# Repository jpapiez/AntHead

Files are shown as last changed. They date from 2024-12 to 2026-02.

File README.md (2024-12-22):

# AntHead
Toolhead for Micron and other PFA printers (Can also work on bigger 2020 based printers with the carriages linked below)


## BOM 
* 2x 4010 blower fans 
* 1x 2510 axial fan 
* various m3 hardware 
* BMG extruder kit , or G2 extruder kit (HGX variant is planned)
* Dragon Compatible hotend, Revo Voron, Rapido, TZV6 with or without v6 nozzle
* NOTE: if using a TZV6 hotend with the stock nozzle (small bambu style nozzle) you need to use the dragon hotend mount

when mounting the fans, the front cover needs to be removed prior to screwing it down with 2 m2x6 


What Carriage Do I Print?

Printer  | Rail 
 ----|----|
Micron/SF/Pandora | Stock [MGN9H](https://github.com/PrintersForAnts/Micron/blob/main/STLs/Gantry/Toolhead/MiniSB/MiniSB_x_carriage_MGN9H_x1.stl) | 
Micron/SF/Pandora | Stock [MGN9C](https://github.com/PrintersForAnts/Micron/blob/main/STLs/Gantry/Toolhead/MiniSB/miniSB_x_carriage_x1.stl) |
Micron/SF/Pandora | Chirpy  [MGN9H](https://github.com/chirpy2605/voron/blob/main/general/Alternative_Voron_Mounts/Modified_Mounts/Micron_Pandora/STLs/X_Carriage_MGN9H_Micron_Long.stl)
Micron/SF/Pandora | Chirpy [MGN9C](https://github.com/chirpy2605/voron/blob/main/general/Alternative_Voron_Mounts/Modified_Mounts/Micron_Pandora/STLs/X_Carriage_MGN9C_Micron_Long.stl)
V0 | Stock works but i recommend Chirpys that can be found [here](https://github.com/chirpy2605/voron/blob/main/general/Alternative_Voron_Mounts/Modified_Mounts/v0.2) 
V2/Trident | Chirpys DB [MGN12H](https://github.com/chirpy2605/voron/tree/main/general/Alternative_Voron_Mounts/Modified_Mounts/V1_V2/STLs/MGN12H)
V2/Trident | Chirpys DB [MGN9H](https://github.com/chirpy2605/voron/tree/main/general/Alternative_Voron_Mounts/Modified_Mounts/V1_V2/STLs/MGN9H)

## Future Plans ##
* HGX Based extruder
* Revisit BMG based extruder
* Bowden option
* Filament cutter (in beta on discord)
* larger variety of hotend mounts

## Change log ##

### 10-30-2024
* Updated CAD to v29
* missed exporting latest right fan ducts from previous commit, they worked but had an extra chamfer that needed to be removed  

### 10-29-2024 #2
* modified main housing to now support Sherpa bolt pattern as well as Orbiter 2 bolt pattern
* ducts were updated to fit the latest change
* a Base Grill cad file was uploaded so custom grills can be made 

### 10-29-2024 #1
* Fixed an issue that was introduced with the latest LED changes from 10-28
* updated main housings, and Cad file

### 10-28-2024
* Updated assembly to v20
* Updated the LED to use the same style as Stealthburner that inserts from the bottom 
* Fixed orientation of various files 

### 10-17-2024
* Added latest CAD assembly
* removed recesses in main housing as they arent needed anymore since hotend mount screws are recessed into the printed part
* added a Voron logo variant of the main body 
* added LED logo parts for both Micron and Voron logo 
* added a dual filament sensor WWG2 variant extruder as the default extruder option in CAD 
* organized files a bit more

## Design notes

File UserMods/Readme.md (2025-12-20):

# Anthead Mods

Various mods for AntHead project
Remember to update this README when uploading new mod!

Update the following table with the information about your mod:
- Your name
- A link to your sub-folder
- A short description of your mod
- On which version of the Anthead is this mod made

| Creator | Mod title | Description | Based on Version
| --- | --- | --- | --- |
| Averen | [LED Solder Fixture](/UserMods/LED_Solder_Fixture) | Fixture for soldering up Nozzle LEDs and Body LED | Version V63 |
| Hoeby | [ZeroClick on left ducting](/UserMods/ZeroClick_left_ducting) | Using ZeroClick on the side, to keep space in the back | Version V43 |
|| [Mainbody HexZero logo](/UserMods/Main_Body_HexZero_logo) | The AntHead mainbody with the HexZero logo, incl. led | Version V43 |
| MakerMylo | [Screwless Hotend Fan Mount](/UserMods/Screwless_Hotend_Fan_Mount) | A mount for the hotend fan that uses pegs to attach to the hotend. | Version V50 |
| theFPVgeek | [Papilio Lite Extruder AntHead Mod](/UserMods/Papilio_Lite_Extruder_AntHead_Mod) | Papilio Lite Extruder modified for AntHead | Version V43 |
| Cyph3r42 | [Wristwatch-BMG dual sensor Extruder](/UserMods/Wristwatch-BMG) | A4T WW-BMG Extruder modified for AntHead | Version V72 |
| burkfers | [Bearing cutting surface](/UserMods/Bearing_cutting_surface) | Uses a small MR63 or 683 bearing as a shearing surface for leafcutter | Version V72 |
| hartk | [Crossbow](/UserMods/hartk/crossbow) | mount to use the crossbow filament cutter | latest |
|| [Trident Umbilical](/UserMods/hartk/Trident_Umbilcal) | umbilical mount for trident| latest |
| Suzuki | [WWG2 V0 Board Mount](/UserMods/WWG2_V0_Board_Mount/) | 4-point board mount for WWG2 on a Voron V0 | Version v96 |

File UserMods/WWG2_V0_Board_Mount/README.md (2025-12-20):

# V0 Board Mount

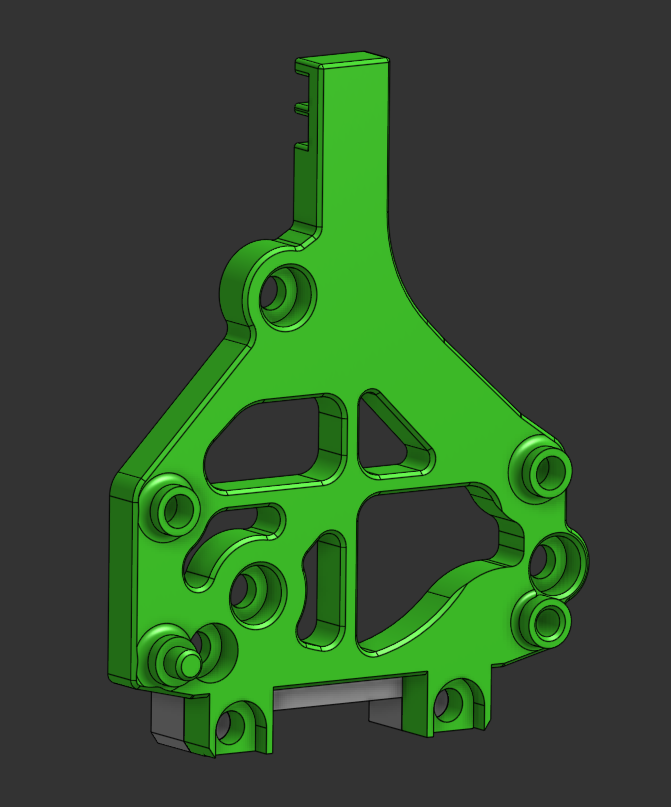
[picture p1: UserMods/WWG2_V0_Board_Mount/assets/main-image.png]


The micron mount colides with the motor mounts in the back, and the 2020 mount isnt rigid enough.

Hardware:

+ Stock hardware
+ 2x M3x12 screws

## Notes

+ There are 2 spacer versions, one for 20mm standoffs, and one for 16mm standoffs. They are `20-Spacer.stl` and `16-Spacer.stl` respectively.
+ The stock P.U.G holder won't work with 16mm standoffs. You'll have to make a custom one.
+ The spacer has to be mounted as shown in the image, or it will colide with the motor mounts.
+ The fit is a bit tight, so don't tighten the screws until they are all in correct positions.

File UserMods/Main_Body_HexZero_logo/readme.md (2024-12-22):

# MainBody with HexZero logo included led option
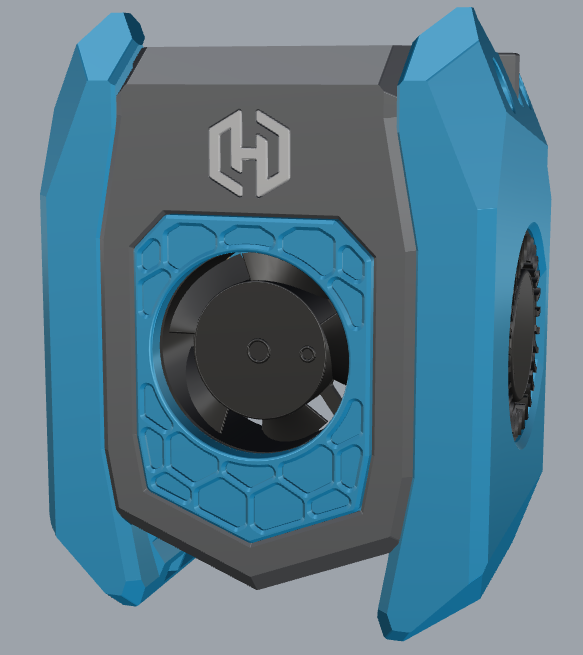
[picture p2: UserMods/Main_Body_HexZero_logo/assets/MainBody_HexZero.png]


This mod is made for the HexZero. <br>
[Github link HexZero](https://github.com/Alexander-T-Moss/Hex-Zero) 

## Which 3d parts are shared
Only the modded parts can be find in this mod. <br>
This includes the parts for the led. <br>
Non modded parts, that are the default AntHead parts and can be find in de main repository of the AntHead. <br>
The parts are made on AntHead version43

## Be carefull
Be carefull when you assemble the led.
Because of the design of the HexZero logo and the space that is availble, the parts are thin.
Take this in care, when you assemble the mainbody.

## Hardware needed for this mode
### For the AntHead
Nothing extra is needed for the AntHead, when looking at the hardware. <br>

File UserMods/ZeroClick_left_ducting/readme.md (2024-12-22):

# ZeroClick on left ducting
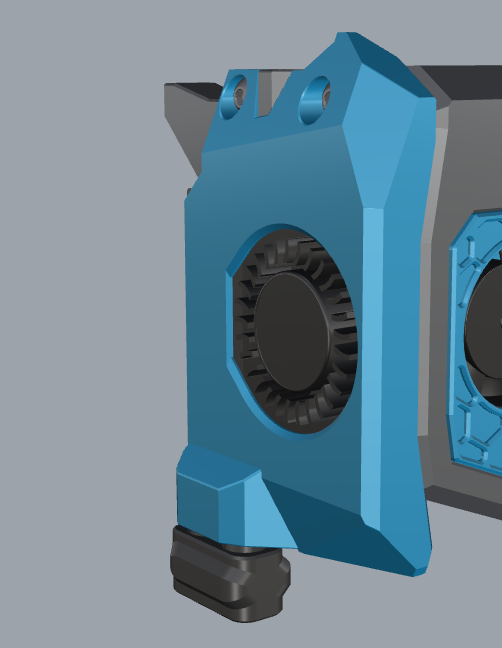
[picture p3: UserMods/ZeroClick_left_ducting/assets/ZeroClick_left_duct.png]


## Idea about this mod
This mod is started for the HexZero. <br>
The HexZero has the dual extrusions in the back, like the Voron V0.2. <br>
On the HexZero the change is made, that the gantry can move over these dual extrusions. <br>
There is that little space, that there can't be parts on the back of the toolhead, because these would collide with these Z-extrusions. <br>
This mod moves the probe to the side, to give free space on the back, to prevent this collision. <br>
[Github link HexZero](https://github.com/Alexander-T-Moss/Hex-Zero) 

## Which 3d parts are shared
Only the modded parts can be find in this mod. <br>
Non modded parts, that are the default AntHead parts and can be find in de main repository of the AntHead. <br>
Only the standard fan is modded. Other fan ductings are not changed, but could be done by de delivered CAD.

## Hardware needed for this mode
### For the AntHead
Nothing extra is needed for the AntHead, when looking at the hardware. <br>
### For the ZeroClick
The default parts for the ZeroClick are needed. <br>
Extra parts could be the parts for the dock, depends on the user choice, what to use. <br>
For the ZeroClick follow there github. <br>
[Github link ZeroClick](https://github.com/zruncho3d/ZeroClick) 

## How to wire the ducting
Before following the ZeroClick manual, the explanation how the wiring has to be done
### Step 1
Start by placing wire in the wire-guide of the front magnet-hole and let it stick out of the back. <br> 
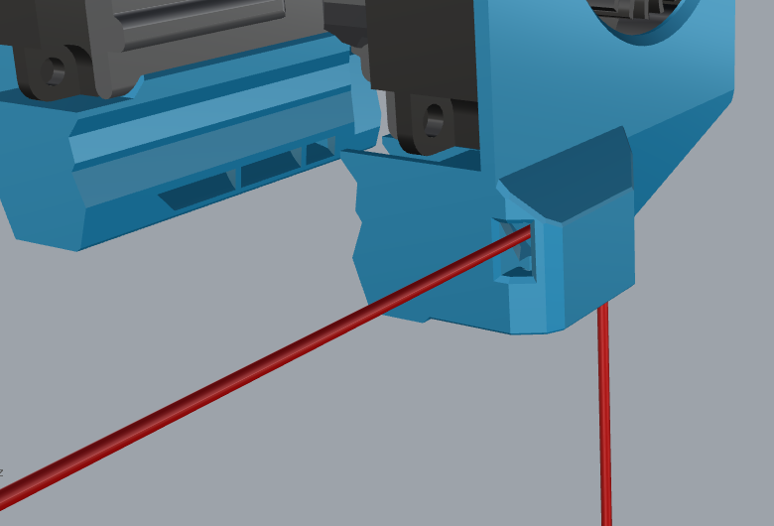
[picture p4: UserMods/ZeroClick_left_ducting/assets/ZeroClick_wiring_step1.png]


### Step 2
Loop back the wire and place it back in the hole it comes out, but now in the wire-guide that goes underneat the fan. <br> 
Carefully pull on the wire end and help them, that the loop disappears inside the ducting, and nothing is sticking out the back. <br>
Not easy to draw in Rhino, to make a wire loop, but you will get it what i mean :blush: <br>
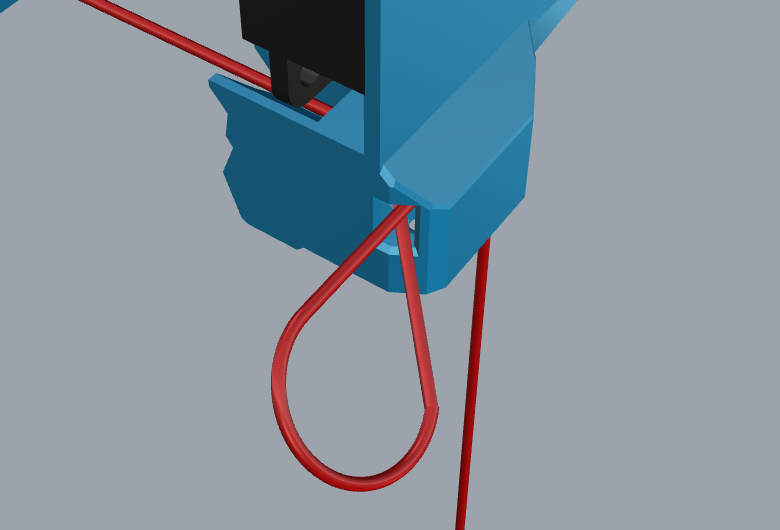
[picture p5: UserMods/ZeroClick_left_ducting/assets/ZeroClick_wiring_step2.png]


### Step 3
Place the wire-guide of the back magnet-hole. <br> 
This wire-guide hole is almost in line with the wire-guide underneat the fan, that you can route it in a single job. <br>
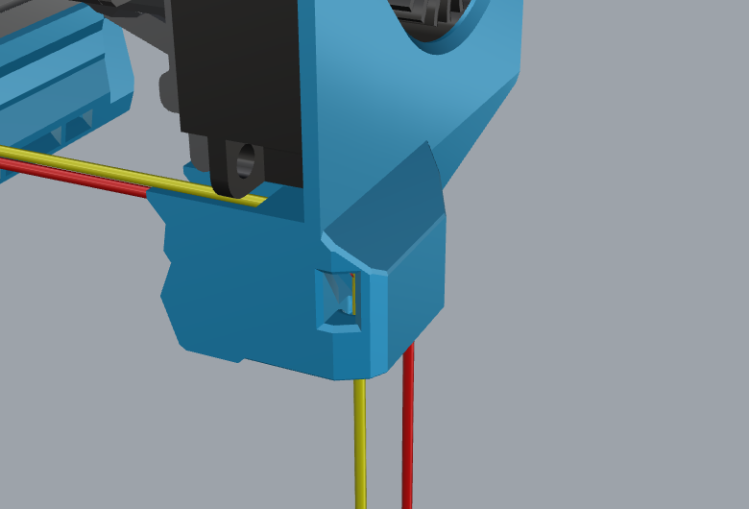
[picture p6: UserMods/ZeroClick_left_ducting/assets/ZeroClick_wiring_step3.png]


### Step 4
Now that the ZeroClick wires are near the fan, follow the wire route of the fan.
How to finish the wiring for the ZeroClick magnets, see the ZeroClick manual on there github

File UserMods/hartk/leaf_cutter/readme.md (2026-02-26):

Leaf Cutter filament cutter. 

This is no longer going to be updated by me (Hartk), with the release of Crossbow CNC cutter that is my recommendation for a filament cutter for anthead. If anyone wants to iterate on this and make it better be my guest , make a PR and ill merge it into this usermods folder

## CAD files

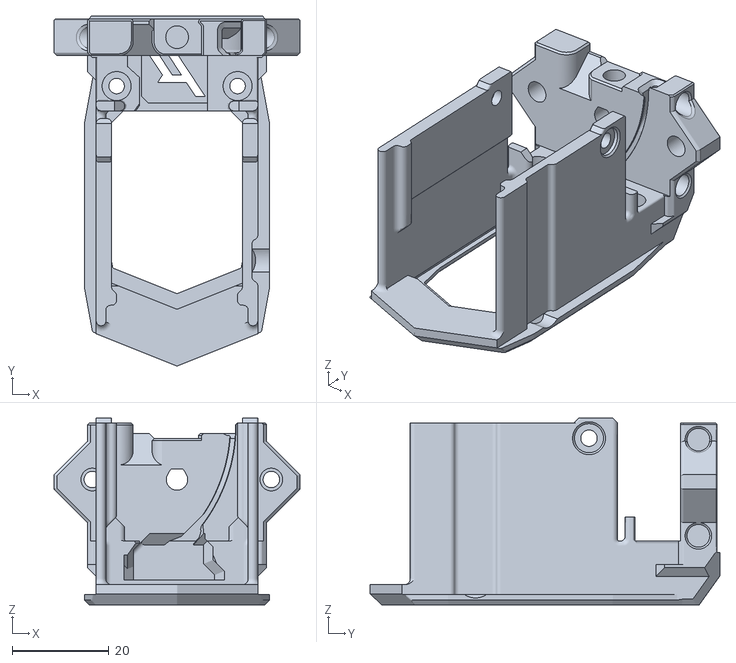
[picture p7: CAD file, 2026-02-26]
STLs/Main_Bodies/O2/Micron/ant_head_main_body_micron_o2_hf_x1.stl
50.8 x 72.3 x 38.6

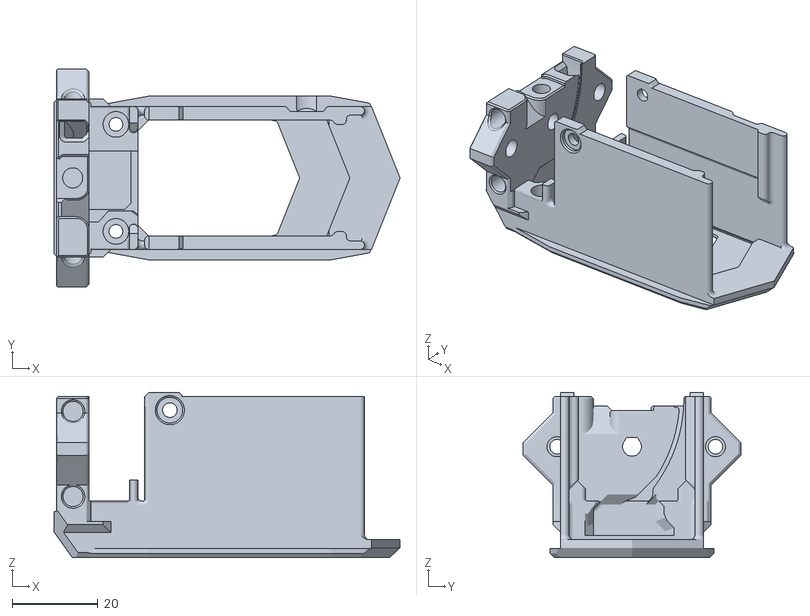
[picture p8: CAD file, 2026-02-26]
STLs/Main_Bodies/O2/No_Logo/ant_head_main_body_no_logo_o2_uhf_x1.stl
80.8 x 50.8 x 38.6

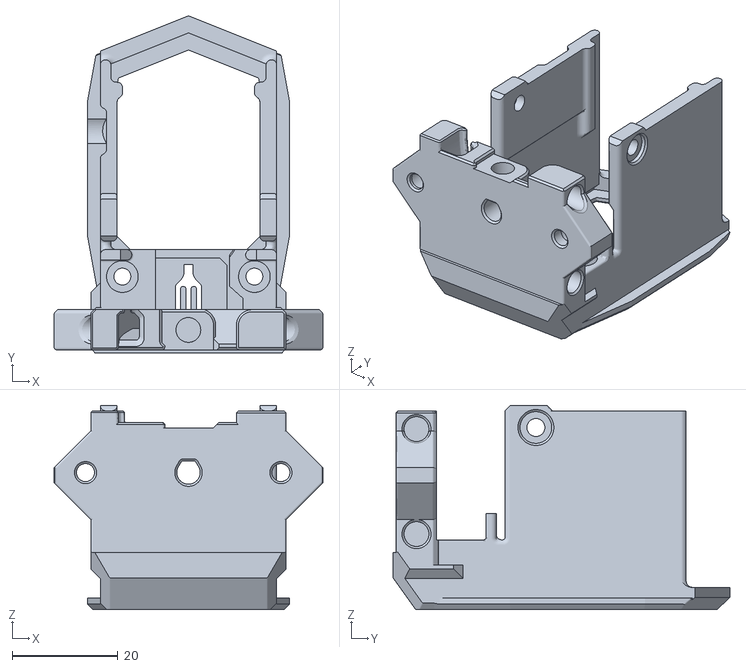
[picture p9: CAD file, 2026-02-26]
STLs/Main_Bodies/O2/SaladFork/ant_head_main_body_saladfork_o2_sf_x1.stl
50.8 x 63.8 x 38.6

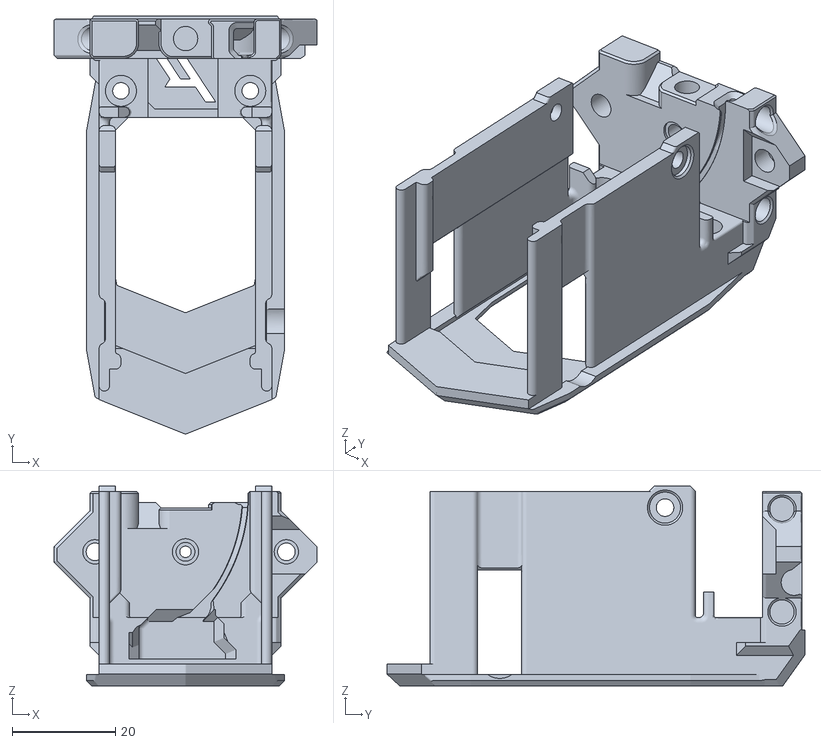
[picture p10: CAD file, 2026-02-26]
UserMods/hartk/leaf_cutter/STLs/Main_Bodies/O2/Micron/ant_head_main_body_micron_o2_uhf_x1.stl
50.8 x 80.8 x 38.6

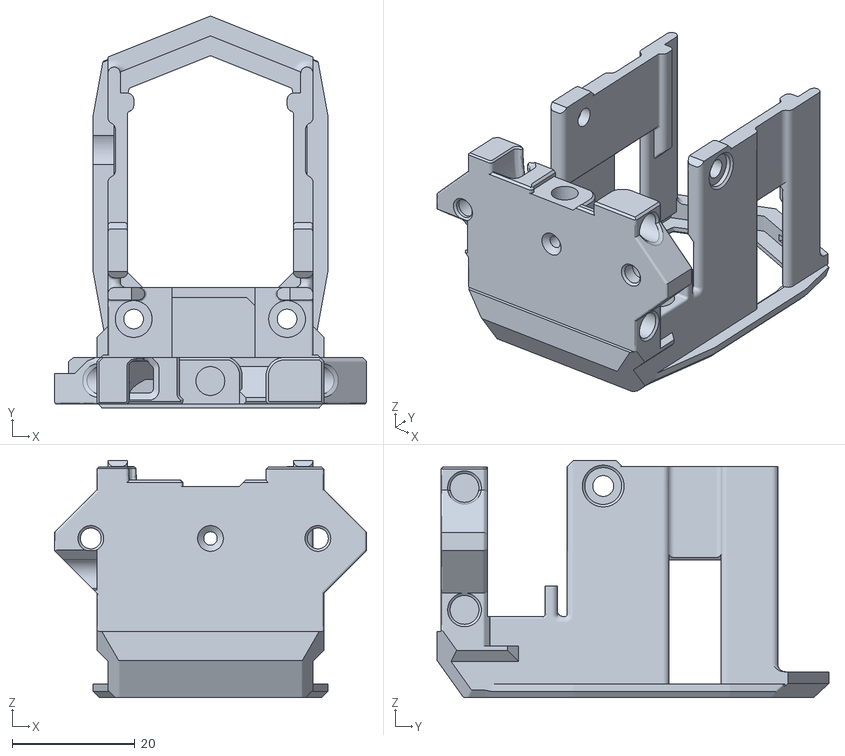
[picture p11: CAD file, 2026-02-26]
UserMods/hartk/leaf_cutter/STLs/Main_Bodies/O2/No_Logo/ant_head_main_body_no_logo_o2_sf_x1.stl
50.8 x 63.8 x 38.6

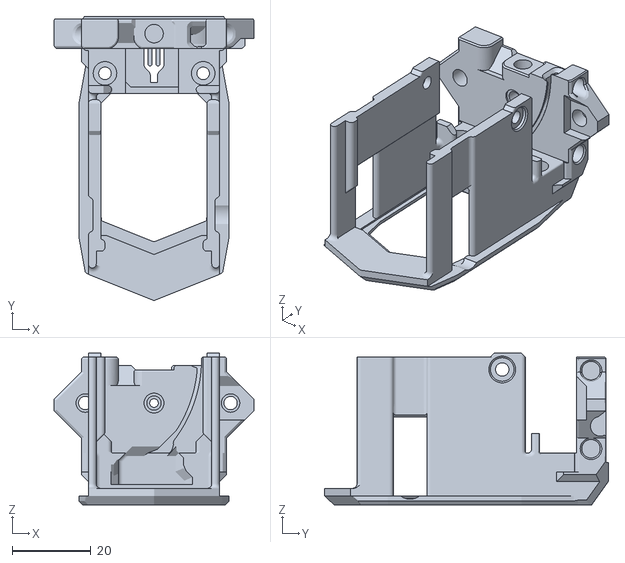
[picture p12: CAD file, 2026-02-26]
UserMods/hartk/leaf_cutter/STLs/Main_Bodies/O2/SaladFork/ant_head_main_body_saladfork_o2_hf_x1.stl
50.8 x 72.3 x 38.6

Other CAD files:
STLs/Main_Bodies/O2/StealthFork/ant_head_main_body_stealth_fork_o2_uhf_x1.stl
STLs/Main_Bodies/O2/Voron/ant_head_main_body_voron_o2_hf_x1.stl
STLs/Main_Bodies/Sherpa/Micron/ant_head_main_body_micron_sherpa_hf_x1.stl
STLs/Main_Bodies/Sherpa/No_Logo/ant_head_main_body_no_logo_sherpa_uhf_x1.stl
STLs/Main_Bodies/Sherpa/SaladFork/ant_head_main_body_saladfork_sherpa_hf_x1.stl
STLs/Main_Bodies/Sherpa/StealthFork/ant_head_main_body_stealth_fork_sherpa_hf_x1.stl
STLs/Main_Bodies/Sherpa/Voron/ant_head_main_body_voron_sherpa_hf_x1.stl
UserMods/hartk/leaf_cutter/STLs/Main_Bodies/O2/StealthFork/ant_head_main_body_stealth_fork_o2_hf_x1.stl
UserMods/hartk/leaf_cutter/STLs/Main_Bodies/O2/Voron/ant_head_main_body_voron_o2_hf_x1.stl
UserMods/hartk/leaf_cutter/STLs/Main_Bodies/Sherpa/Micron/ant_head_main_body_micron_sherpa_hf_x1.stl
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

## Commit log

2024-12-03 Adding additional hotend mounts
    [[a]_bambu_x1.stl, [a]_dragon-ace-x1.stl]
2025-12-20 added wwg2 v0 board mount to usermods
    [16-Spacer.stl, 20-Spacer.stl, WWG2-V0-Board-Mount.step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]
2026-01-07 updated cad to the latest version
2026-01-15 updated crossbow depressor arm and extruder front body
    [[a]_depressor_arm.stl, [a]_depressor_arm_stock.stl, [a]_depressor_arm_vitali_carriage.stl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]
2026-02-26 removed leaf cutter from stock build, moved to a usermod , leafcutter is no longer getting updated after this
    [[a]_26mm_blade_holder_x1.stl, [a]_chube_for_ants_M2.5_x1.stl, [a]_chube_for_ants_finn_M2.5_x1.stl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]
